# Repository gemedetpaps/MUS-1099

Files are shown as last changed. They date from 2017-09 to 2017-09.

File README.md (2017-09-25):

# MUS-1099
ISA sound card based on the SAA1099 sound generator

This card is based on the work by Sergey and Tronix of the Vintage Computer Federation forums and is an attempt at 
creating a working clone of the Creative CMS / Game Blaster ISA cards.

More information can be found at http://www.vcfed.org/forum/showthread.php?59846-Creative-Music-System-Game-Blaster-clone

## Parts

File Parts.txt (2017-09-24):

Part     Value
C1       10 uF Tantalum Capacitor
C2       .1 uF Ceramic Capacitor
C3       .1 uF Ceramic Capacitor
C4       .1 uF Ceramic Capacitor
C5       .1 uF Ceramic Capacitor
C6       .1 uF Ceramic Capacitor
C7       .1 uF Ceramic Capacitor
C8       .1 uF Ceramic Capacitor
C9       .1 uF Ceramic Capacitor
C10      .1 uF Ceramic Capacitor
C11      680 pF Ceramic Capacitor
C12      680 pF Ceramic Capacitor
C13      680 pF Ceramic Capacitor
C14      680 pF Ceramic Capacitor
C15      .22 uF Ceramic Capacitor
C16      .22 uF Ceramic Capacitor
C17      100 uF Electrolytic Capacitor
C18      100 uF Electrolytic Capacitor
C19      100 uF Electrolytic Capacitor
C20      100 uF Electrolytic Capacitor
C21      100 uF Electrolytic Capacitor
C22      100 uF Electrolytic Capacitor
C23      .15 uF Ceramic Capacitor
C24      .15 uF Ceramic Capacitor
C25      470 uF Electrolytic Capacitor
C26      470 uF Electrolytic Capacitor
IC1      74LS32
IC2      74LS245
IC3      74LS138
IC4      74LS138
IC5      74LS374
IC6      74LS74
IC7      SAA1099
IC8      SAA1099
IC9      TEA2025
JP1      6x2 pin header
R1       1k 1/4 W
R2       10k 1/4 W
R3       10k 1/4 W
R4       1.5k 1/4 W
R5       1.5k 1/4 W
R6       10k 1/4 W
R7       10k 1/4 W
R8       10K dual audio taper potentiometer
RN1      8 pin 4.7K bussed SIP resistor network
X1       3.5mm stereo audio jack
Bracket  Keystone 9202 EISA/ISA PCB Bracket

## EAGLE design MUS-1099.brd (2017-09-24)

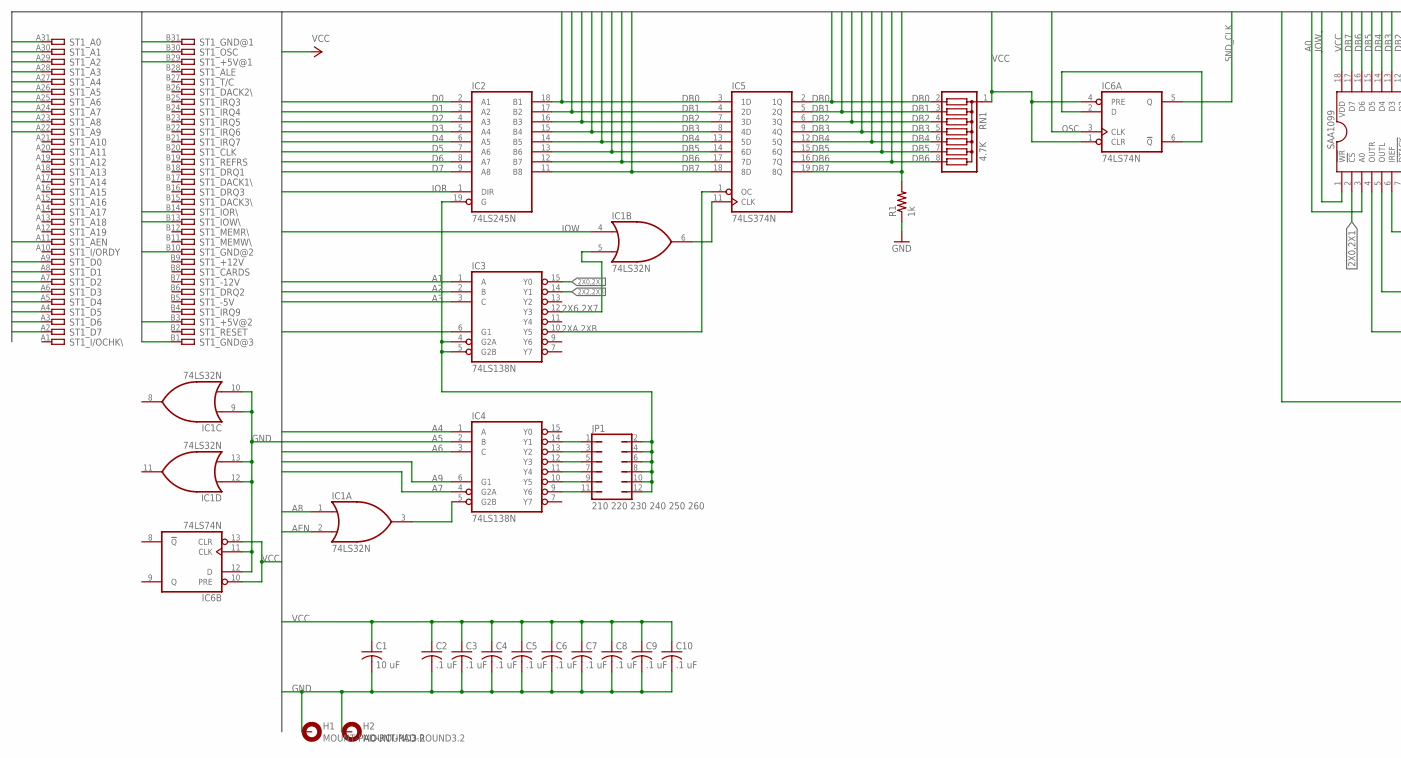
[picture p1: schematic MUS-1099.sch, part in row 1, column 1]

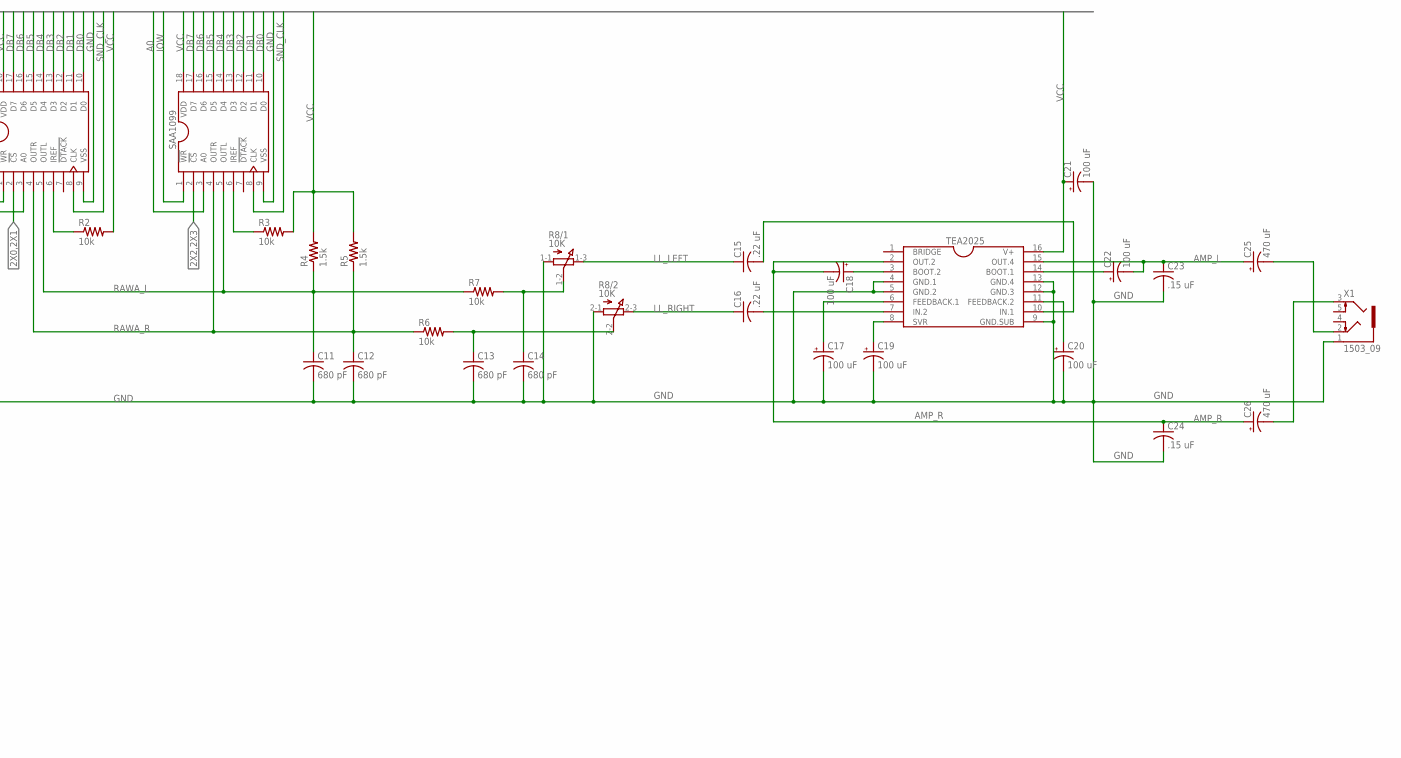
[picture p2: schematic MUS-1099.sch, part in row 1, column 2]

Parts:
C1: 10 uF; C025-025X050
C2, C3, C4, C5, C6, C7, C8, C9, C10: .1 uF; C025-025X050
C11, C12, C13, C14: 680 pF; C025-025X050
C15, C16: .22 uF; C025-025X050
C17, C18, C19, C20, C21, C22: 100 uF; E5-10,5
C23, C24: .15 uF; C025-025X050
C25, C26: 470 uF; E5-10,5
H1, H2: MOUNT-PAD-ROUND3.2; 3,2-PAD
IC1: 74LS32N; DIL14
IC2: 74LS245N; DIL20
IC3, IC4: 74LS138N; DIL16
IC5: 74LS374N; DIL20
IC6: 74LS74N; DIL14
IC7, IC8: SAA1099; DIL18
IC9: TEA2025; DIL16
JP1: 210 220 230 240 250 260; JP6Q
R1: 1k; 0207/10
R2, R3, R6, R7: 10k; 0207/10
R4, R5: 1.5k; 0207/10
R8: 10K; 3RP/1610G
RN1: 4.7K; SIL8
ST1: 8 bit ISA; IBM8BIT
X1: 1503_09

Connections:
2X0,2X1: IC3.15 (Y0), IC7.2 (!CS!)
2X2,2X3: IC3.14 (Y1), IC8.2 (!CS!)
2X6,2X7: IC1.5 (I1), IC3.12 (Y3)
2XA,2XB: IC3.10 (Y5), IC5.1 (OC)
A0: IC7.3 (A0), IC8.3 (A0), ST1.A31
A1: IC3.1 (A), ST1.A30
A2: IC3.2 (B), ST1.A29
A3: IC3.3 (C), ST1.A28
A4: IC4.1 (A), ST1.A27
A5: IC4.2 (B), ST1.A26
A6: IC4.3 (C), ST1.A25
A7: IC4.4 (G2A), ST1.A24
A8: IC1.1 (I0), ST1.A23
A9: IC4.6 (G1), ST1.A22
AEN: IC1.2 (I1), ST1.A11
AMP_L: C22.-, C23.1, C25.+, IC9.15 (OUT.4)
AMP_R: C18.-, C24.1, C26.+, IC9.2 (OUT.2)
D0: IC2.2 (A1), ST1.A9
D1: IC2.3 (A2), ST1.A8
D2: IC2.4 (A3), ST1.A7
D3: IC2.5 (A4), ST1.A6
D4: IC2.6 (A5), ST1.A5
D5: IC2.7 (A6), ST1.A4
D6: IC2.8 (A7), ST1.A3
D7: IC2.9 (A8), ST1.A2
DB0: IC2.18 (B1), IC5.2 (1Q), IC5.3 (1D), IC7.10 (D0), IC8.10 (D0), RN1.2
DB1: IC2.17 (B2), IC5.4 (2D), IC5.5 (2Q), IC7.11 (D1), IC8.11 (D1), RN1.3
DB2: IC2.16 (B3), IC5.6 (3Q), IC5.7 (3D), IC7.12 (D2), IC8.12 (D2), RN1.4
DB3: IC2.15 (B4), IC5.8 (4D), IC5.9 (4Q), IC7.13 (D3), IC8.13 (D3), RN1.5
DB4: IC2.14 (B5), IC5.12 (5Q), IC5.13 (5D), IC7.14 (D4), IC8.14 (D4), RN1.6
DB5: IC2.13 (B6), IC5.14 (6D), IC5.15 (6Q), IC7.15 (D5), IC8.15 (D5), RN1.7
DB6: IC2.12 (B7), IC5.16 (7Q), IC5.17 (7D), IC7.16 (D6), IC8.16 (D6), RN1.8
DB7: IC2.11 (B8), IC5.18 (8D), IC5.19 (8Q), IC7.17 (D7), IC8.17 (D7), R1.2
GND: C1.2, C2.2, C3.2, C4.2, C5.2, C6.2, C7.2, C8.2, C9.2, C10.2, C11.2, C12.2, C13.2, C14.2, C17.-, C19.-, C20.-, C21.-, C23.2, C24.2, H1.B3,2, H2.B3,2, IC1.7 (GND), IC1.9 (I0), IC1.10 (I1), IC1.12 (I0), IC1.13 (I1), IC2.10 (GND), IC3.8 (GND), IC4.8 (GND), IC5.10 (GND), IC6.7 (GND), IC6.11 (CLK), IC6.12 (D), IC7.9 (VSS), IC8.9 (VSS), IC9.4 (GND.1), IC9.5 (GND.2), IC9.9 (GND.SUB), IC9.12 (GND.3), IC9.13 (GND.4), R1.1, R8.1-1 (A), R8.2-1 (A), ST1.B1, ST1.B10, ST1.B31, X1.1
IOR: IC2.1 (DIR), ST1.B14
IOW: IC1.4 (I0), IC7.1 (!WR!), IC8.1 (!WR!), ST1.B13
LL_LEFT: C15.1, R8.1-3 (E)
LL_RIGHT: C16.1, R8.2-3 (E)
N210: IC4.14 (Y1), JP1.1
N220: IC4.13 (Y2), JP1.3
N230: IC4.12 (Y3), JP1.5
N240: IC4.11 (Y4), JP1.7
N250: IC4.10 (Y5), JP1.9
N260: IC4.9 (Y6), JP1.11
unnamed: IC1.3 (O), IC4.5 (G2B)
unnamed: IC2.19 (G), IC3.4 (G2A), IC3.5 (G2B), JP1.2, JP1.4, JP1.6, JP1.8, JP1.10, JP1.12
unnamed: IC1.6 (O), IC5.11 (CLK)
unnamed: IC6.2 (D), IC6.6 (!Q)
unnamed: C13.1, R6.2, R8.2-2 (S)
unnamed: C14.1, R7.2, R8.1-2 (S)
unnamed: IC7.6 (IREF), R2.1
unnamed: IC8.6 (IREF), R3.1
unnamed: C16.2, IC9.7 (IN.2)
unnamed: C15.2, IC9.10 (IN.1)
unnamed: C17.+, IC9.6 (FEEDBACK.1)
unnamed: C20.+, IC9.11 (FEEDBACK.2)
unnamed: C25.-, X1.2
unnamed: C26.-, X1.3
unnamed: C19.+, IC9.8 (SVR)
unnamed: C22.+, IC9.14 (BOOT.1)
unnamed: C18.+, IC9.3 (BOOT.2)
OSC: IC6.3 (CLK), ST1.B30
RAWA_L: C11.1, IC7.5 (OUTL), IC8.5 (OUTL), R4.1, R7.1
RAWA_R: C12.1, IC7.4 (OUTR), IC8.4 (OUTR), R5.1, R6.1
SND_CLK: IC6.5 (Q), IC7.8 (CLK), IC8.8 (CLK)
VCC: C1.1, C2.1, C3.1, C4.1, C5.1, C6.1, C7.1, C8.1, C9.1, C10.1, C21.+, IC1.14 (VCC), IC2.20 (VCC), IC3.6 (G1), IC3.16 (VCC), IC4.16 (VCC), IC5.20 (VCC), IC6.1 (CLR), IC6.4 (PRE), IC6.10 (PRE), IC6.13 (CLR), IC6.14 (VCC), IC7.18 (VDD), IC8.18 (VDD), IC9.16 (V+), R2.2, R3.2, R4.2, R5.2, RN1.1, ST1.B3, ST1.B29

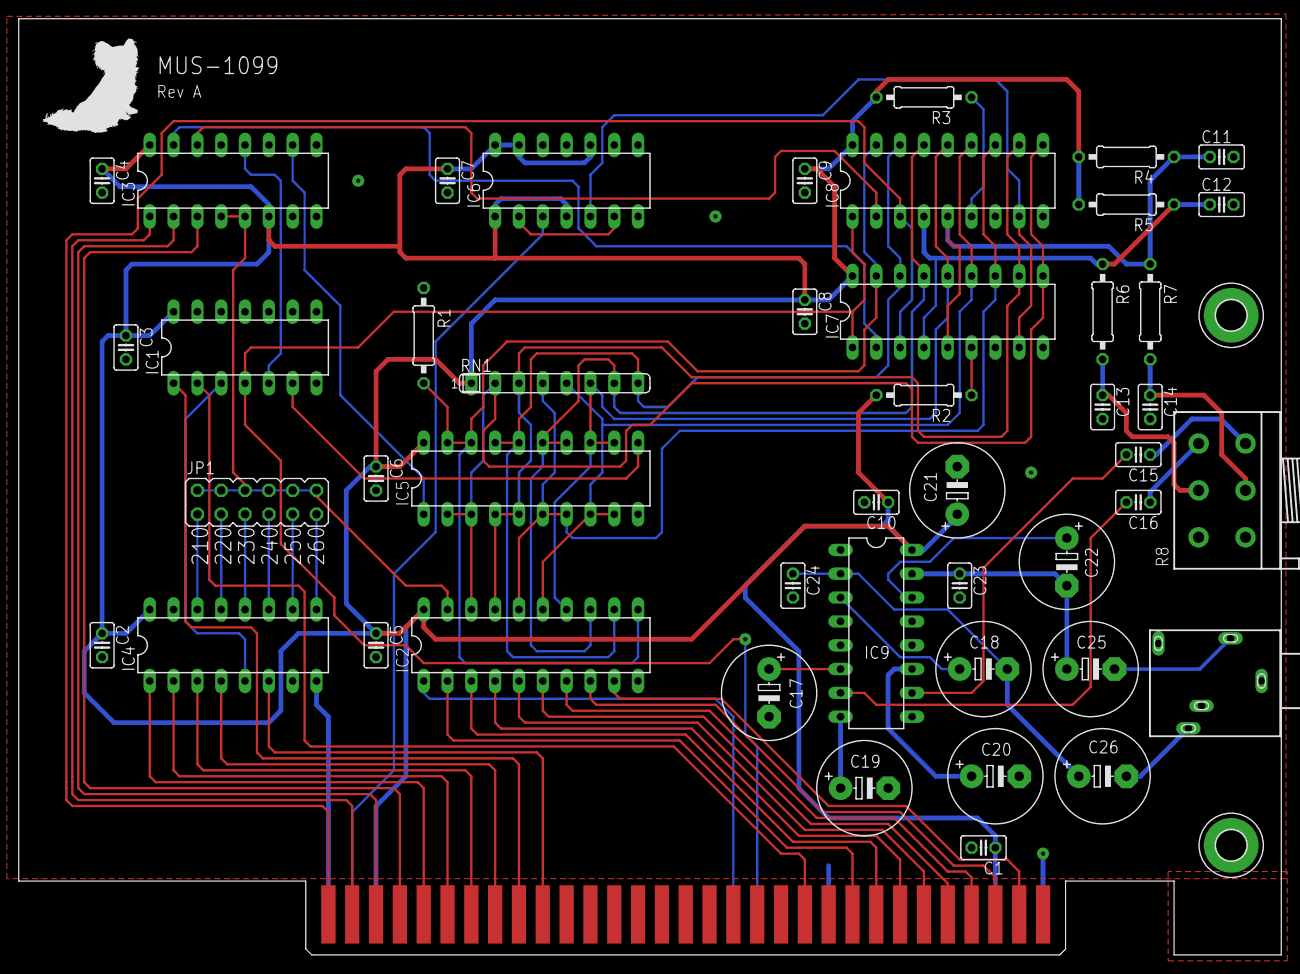
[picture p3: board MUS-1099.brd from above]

Board: 2 copper layers, 134.6 x 99.8 mm, 50 parts (0 on the bottom side), 66 nets.

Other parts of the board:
U$1: LOGO

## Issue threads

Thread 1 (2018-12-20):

Which potentiometer and audio jack to be used?

root42, 2018-12-20:
I have gotten my PCBs and also some components according to the BOM. However I found it hard to find fitting potentiometers and audio jacks. The potis I have got are a bit tall, although the footprint matches. I haven't got any fitting audio jacks so far.

Can you give some model numbers, please?

root42, 2018-12-20:
Ok, I THINK I found at least an audio jack:

https://www.mouser.de/ProductDetail/CUI/SJ1-3515N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

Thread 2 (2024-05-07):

Port back community improvements

germanviscuso, 2024-05-07:
In the Vogons thread related to this board there are several improvements that have been made to this board. The most notable that maintain a non-SMD design where done bt @davidmorom here:
https://www.vogons.org/viewtopic.php?p=1120829#p1120829
Suggested improvements then to port back to this project are:

- Modify the potentiometer layout to fit a common RK097G, which can be easily found on Aliexpress.
- Modified the potentiometer connection to the more common way of outputting the signal trough the central tap.
- Added 1k resistors on the gain loop of the TEA2025 amplifier. This reduces the gain from 200 (46dB, which is crazy) to 9.5 (19dB), as the original CMS card (the 1k resistors can be seen on pictures of the original card).
- A lot of cosmetic changes: moved some components and traces, texts, logo, component labels, etc
- And last, but most important of all, added a 78L05 linear regulator to generate a clean +5V rail to feed the SAA1099 output pull-ups and reference current inputs. This completely eliminates the annoying power supply interference, and gives very good sound quality, with the noise level expectable for an almost 40 years old hardware.

Photo: https://www.vogons.org/download/file.php?id=151252&mode=view
Eagle files and gerbers: https://www.vogons.org/download/file.php?id=192366
(Vogons user required for download)
